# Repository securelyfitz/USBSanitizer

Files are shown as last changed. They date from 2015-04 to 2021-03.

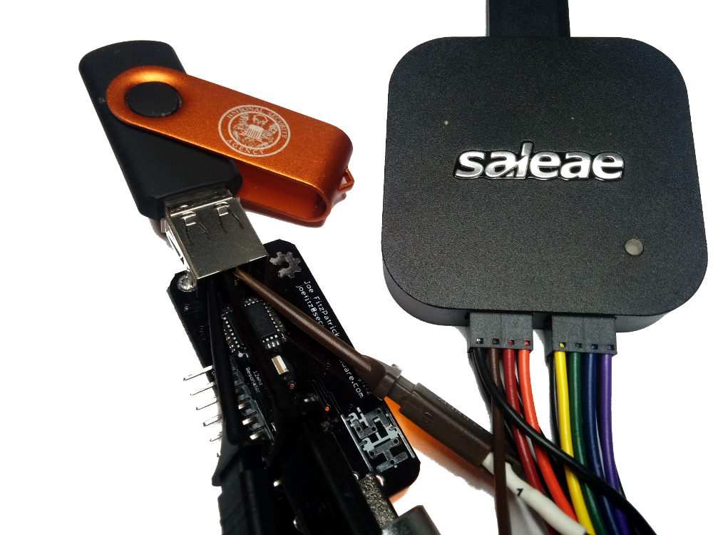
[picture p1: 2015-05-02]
Hushcon East/img/saleae.png

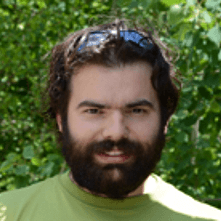
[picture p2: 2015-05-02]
Hushcon East/img/joe.png

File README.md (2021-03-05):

USB Sanitizer
================

A small and cheap standalone USB drive wiper

The code is based heavily on the USBHostGeneric example from FTDI as well as USB-Writeblocker by Phil Polstra

View 'slides' from hushcon:
https://rawgit.com/securelyfitz/USBSanitizer/master/Hushcon%20East/Hushcon%20East%20-%20USBSanitizer%20presentation.html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

Disclaimer:
-----------
USB sanitizer has some issues with a large number of USB drives right now. I should have an update shortly once i properly probe the SCSI device status/ready commands before writing...

Overview
---------
USB has issues, and being a very layered architecture, has layers of issues.

I deal with distributing class material on USB drives at security conferences, and prefer to reuse drives. At first i had a standalone air-gapped PC that did the job automatically when a drive was inserted, and more recently i have used a pogoplug modified for the purpose. This is overkill, and it's also not any guarantee that my air-gapped system that never gets any updates isn't vulnerable  to layers of potentially exploitable bugs.

After seeing how USB drives are used to transport information to air-gapped computers and learning that many securedrop sites use USB drives to transfer data to air-gapped computers, i realized that there is a broader use for a simple, standalone USB drive wiper.

Objective
---------
I aimed for a device that was:
- small (no larger than a usb drive itself)
- cheap ($5-10 BOM)
- bare metal (little or no OS)
- easy to build (Leaded SMT, single chip if possible)
- easy to code (cause i am teh suk at codez)
- easy to program ($50 programmer for a $5 board is lame)
 
Hardware
--------
- The main IC is the FTDI VNC2 which has a proprietary harvard architecture, proprietary 'RTOS', built in flash, and built in usb host capability. No other chip that i found under $10 had all that on a single chip.
- The board is 2.5x5cm. In addition to the VNC2, there is a single voltage regulator, a resonator, and a bunch of passive devices.
- Power is provided by the USB Male connector. Data pins are not connected to this connector in a normal build. If connected, this device can also be used with Phil Polstra's USB-Writeblocker: https://github.com/ppolstra/USB-Writeblocker
- A USB Female connector receives the flash drive (or even usb hdd/ssd).
- There is a 9 pin header for programming that can be unpopulated for production devices. Programming can be done via standard UART with hardware flow control.

Software
--------
FTDI provides an IDE and compiler for the VNC2 for windows only. It didn't run well on WINE on my initial attempts. The IDE can only be downloaded from them, without SSL. FTDI doesn't provide hashes of the executables either. If you're lucky enough to get the same embedded malware as me, your MD5s should be:
- http://www.ftdichip.com/Firmware/vnc2toolchain/Vinculum%20II%20Installer%20V2.0.0-SP1.exe
7b60bdc4313ed0449374dcaab23e0e84 
- http://www.ftdichip.com/Support/Utilities/VPROG.zip
ab5ec25792ef7a4f780aa507cd326ba5 
- http://www.ftdichip.com/Support/Utilities/FT_Prog_v3.0.60.276%20Installer.zip
f9a62778065ca541005dd138a52c5c99

FTDI provides an API for doing some basic USB stuff. They've got APIs to navigate filesystems and play audio files, but they're missing the ability to do basic things like query the capacity of a block storage device. Because of this i basically wrote everything at the raw USB level. I let the FTDI library take care of ACKs and NAKs but otherwise do most of the data transfer myself.

Everything about the VINCULUM is flakey - the IDE, the compiler, the hardware, the architecture in general. In retrospect there are probably more exploitable bugs in this bare-bones embedded device than there were in my air-gapped PC.

PCB Files
---------
* .sch and .brd: eagle schematic and board files 
* .lbr: eagle libraries for board outline and text items 
* .G* and .TXT: gerber files for fabricating board

Building:
------------------
See a video of building up a prototype. V1.0 is essentially the same, with the addition of a reset switch.

https://www.youtube.com/watch?v=V60TksZd7uk

Bill of Materials for ordering at digikey is in [USBSanitizer.csv]. Cost is $8.60 for a single set.

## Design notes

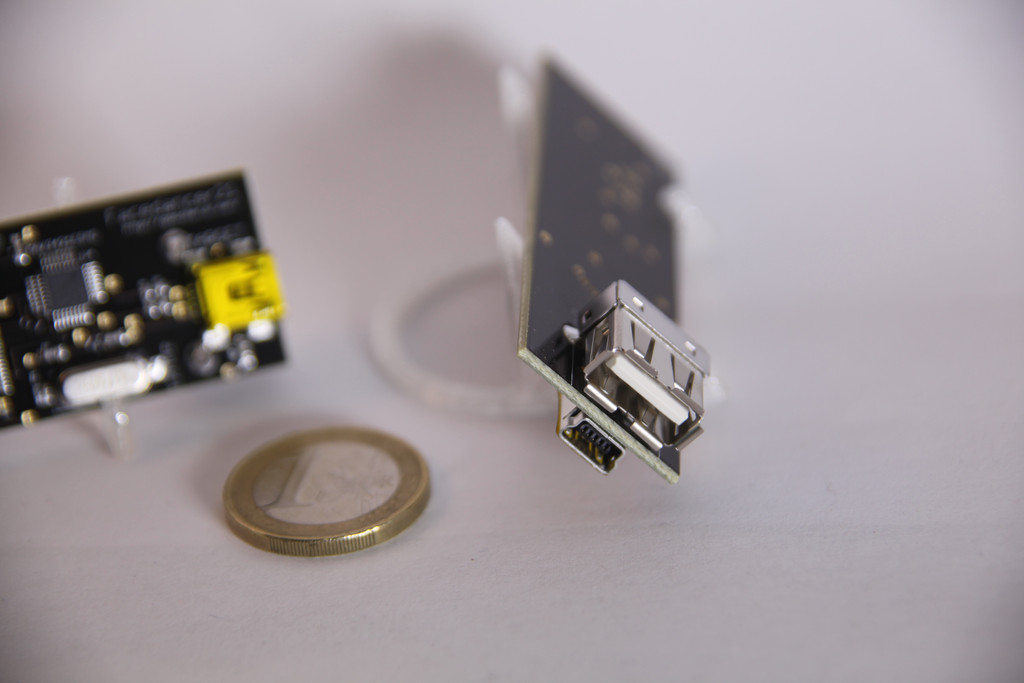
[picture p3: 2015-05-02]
Hushcon East/img/facedancer.jpg

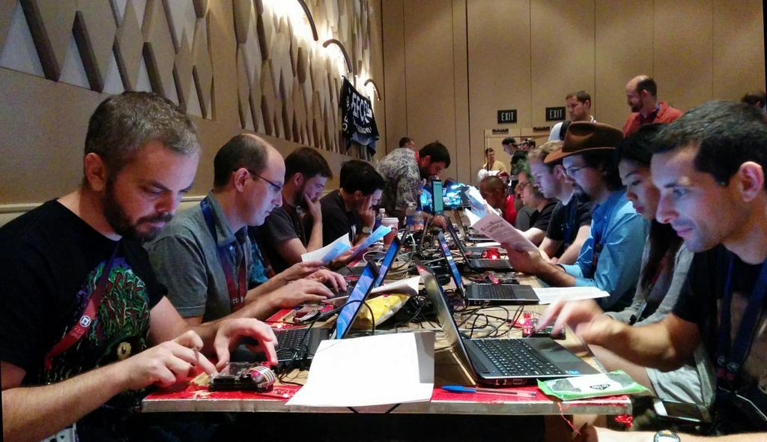
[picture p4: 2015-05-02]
Hushcon East/img/defcon.jpg

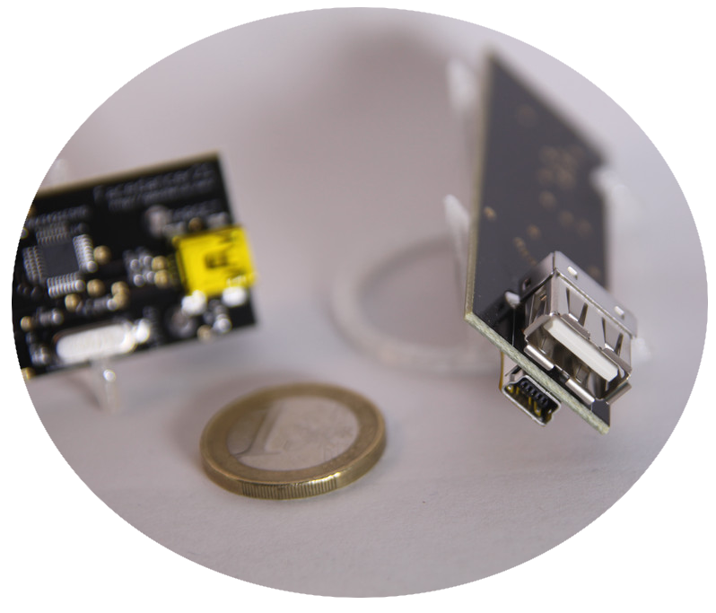
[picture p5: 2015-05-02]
Hushcon East/img/facedancer.png

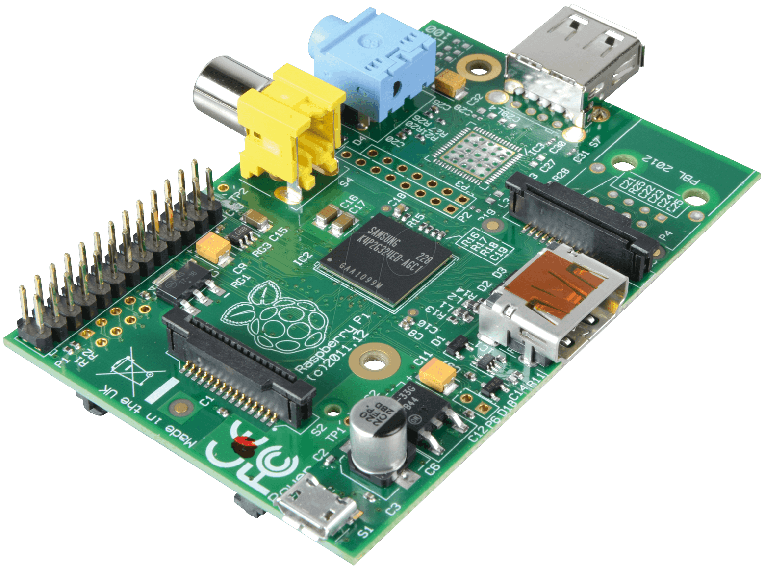
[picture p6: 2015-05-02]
Hushcon East/img/rpi.png

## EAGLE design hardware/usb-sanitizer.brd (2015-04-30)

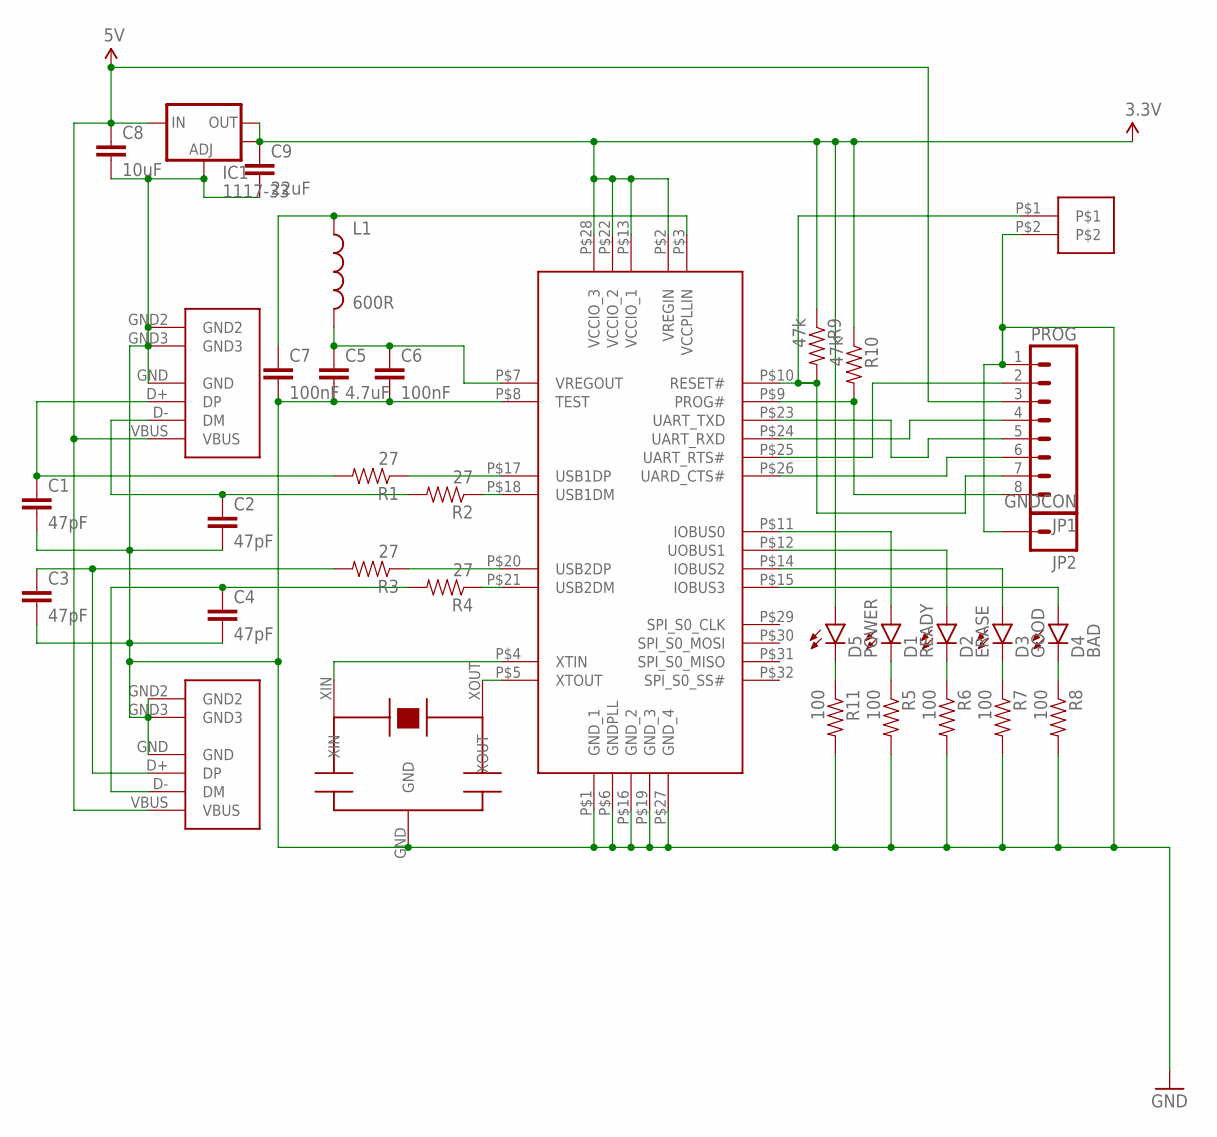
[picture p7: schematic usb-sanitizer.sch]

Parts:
C1, C2, C3, C4: 47pF; 0805
C5: 4.7uF; 0805
C6, C7: 100nF; 0805
C8: 10uF; 0805
C9: 22uF; 0805
D1: READY; 0805
D2: ERASE; 0805
D3: GOOD; 0805
D4: BAD; 0805
D5: POWER; 0805
IC1: 1117-33; SOT223
JP1: PROG; 1X08_LOCK
JP2: GNDCON; 1X01
L1: 600R; 0805
R1, R2, R3, R4: 27; 0805
R5, R6, R7, R8, R11: 100; 0805
R9, R10: 47k; 0805
U$1: VNC2; QFP32
U$4: RESONATOR
U$5: SWITCH
USB_FEMALE: USB_AF; USB-A-F
USB_MALE: USB_AM; USB-A-M

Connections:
3.3V: C9.1, D5.1 (A), IC1.2 (OUT), IC1.4 (OUT), R9.1, R10.1, U$1.P$2 (VREGIN), U$1.P$13 (VCCIO_1), U$1.P$22 (VCCIO_2), U$1.P$28 (VCCIO_3)
5V: C8.1, IC1.3 (IN), JP1.3, USB_FEMALE.VBUS, USB_MALE.VBUS
GND: C1.2, C2.2, C3.2, C4.2, C5.2, C6.2, C7.2, C8.2, C9.2, IC1.1 (ADJ), JP1.1, JP2.1, R5.2, R6.2, R7.2, R8.2, R11.2, U$1.P$1 (GND_1), U$1.P$6 (GNDPLL), U$1.P$8 (TEST), U$1.P$16 (GND_2), U$1.P$19 (GND_3), U$1.P$27 (GND_4), U$4.GND, U$5.P$2, USB_FEMALE.GND, USB_FEMALE.GND2, USB_FEMALE.GND3, USB_MALE.GND, USB_MALE.GND2, USB_MALE.GND3
unnamed: D5.2 (C), R11.1
unnamed: C5.1, C6.1, L1.2, U$1.P$7 (VREGOUT)
unnamed: C7.1, L1.1, U$1.P$3 (VCCPLLIN)
unnamed: U$1.P$5 (XTOUT), U$4.XOUT
unnamed: U$1.P$4 (XTIN), U$4.XIN
unnamed: JP1.2, U$1.P$25 (UART_RTS#)
unnamed: JP1.4, U$1.P$24 (UART_RXD)
unnamed: JP1.5, U$1.P$23 (UART_TXD)
unnamed: JP1.6, U$1.P$26 (UARD_CTS#)
unnamed: JP1.8, R10.2, U$1.P$9 (PROG#)
unnamed: JP1.7, R9.2, U$1.P$10 (RESET#), U$5.P$1
unnamed: D1.2 (C), R5.1
unnamed: D2.2 (C), R6.1
unnamed: D4.2 (C), R8.1
unnamed: D3.2 (C), R7.1
unnamed: D1.1 (A), U$1.P$11 (IOBUS0)
unnamed: D2.1 (A), U$1.P$12 (UOBUS1)
unnamed: D3.1 (A), U$1.P$14 (IOBUS2)
unnamed: D4.1 (A), U$1.P$15 (IOBUS3)
USB1DM: R2.1, U$1.P$18 (USB1DM)
USB1DP: R1.1, U$1.P$17 (USB1DP)
USB1RDM: C2.1, R2.2, USB_FEMALE.D- (DM)
USB1RDP: C1.1, R1.2, USB_FEMALE.D+ (DP)
USB2DM: R4.1, U$1.P$21 (USB2DM)
USB2DP: R3.1, U$1.P$20 (USB2DP)
USB2RDM: C4.1, R4.2, USB_MALE.D- (DM)
USB2RDP: C3.1, R3.2, USB_MALE.D+ (DP)

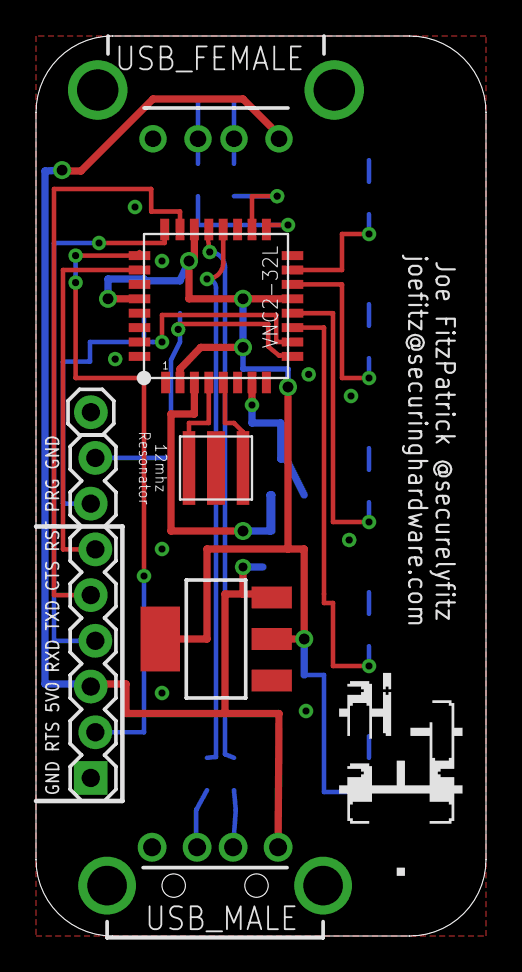
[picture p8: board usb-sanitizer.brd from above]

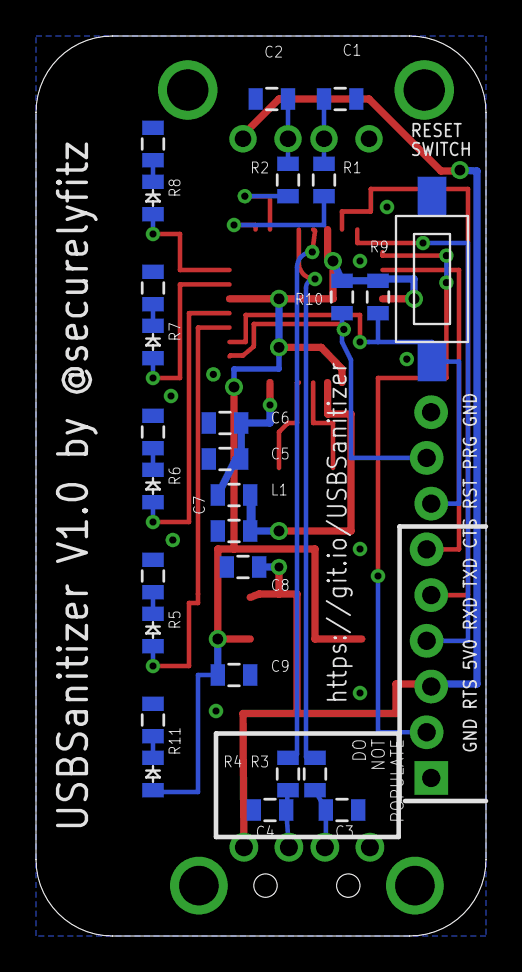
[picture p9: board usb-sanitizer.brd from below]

Board: 2 copper layers, 25.0 x 50.0 mm, 36 parts (27 on the bottom side), 30 nets.

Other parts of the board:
U$2: SH-HALFINCH
U$3: OSHW

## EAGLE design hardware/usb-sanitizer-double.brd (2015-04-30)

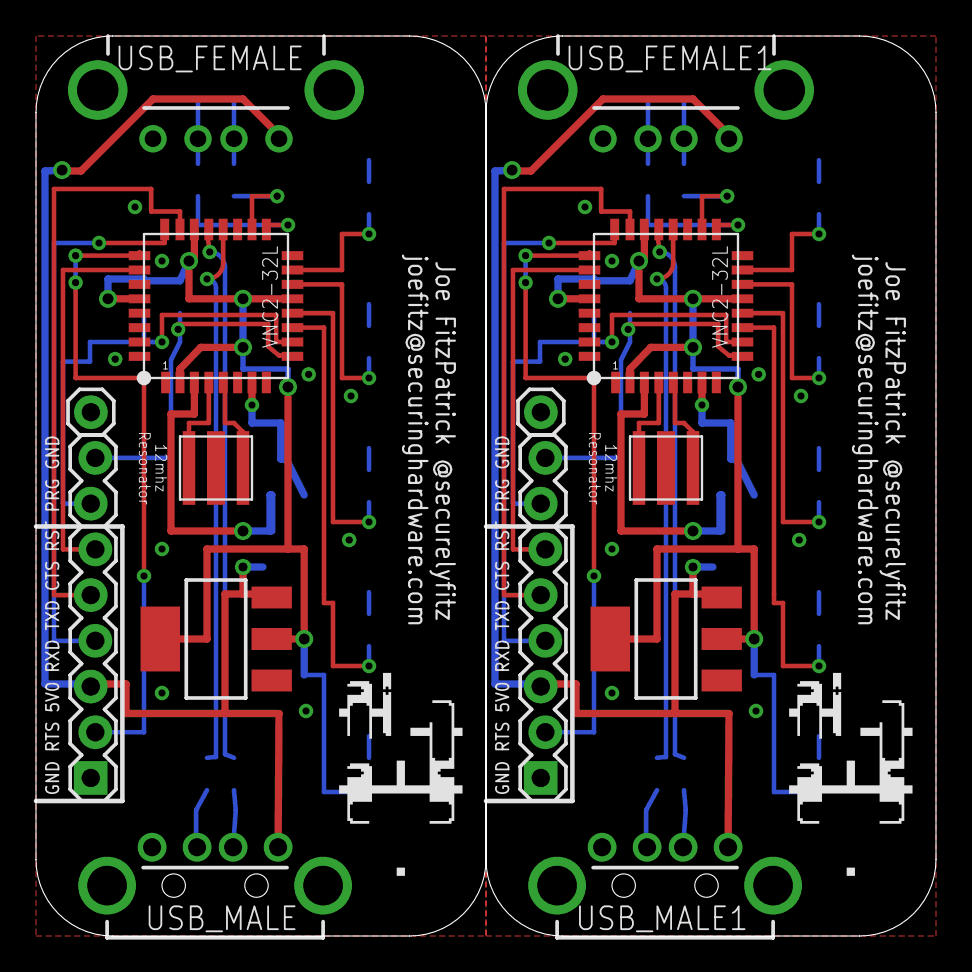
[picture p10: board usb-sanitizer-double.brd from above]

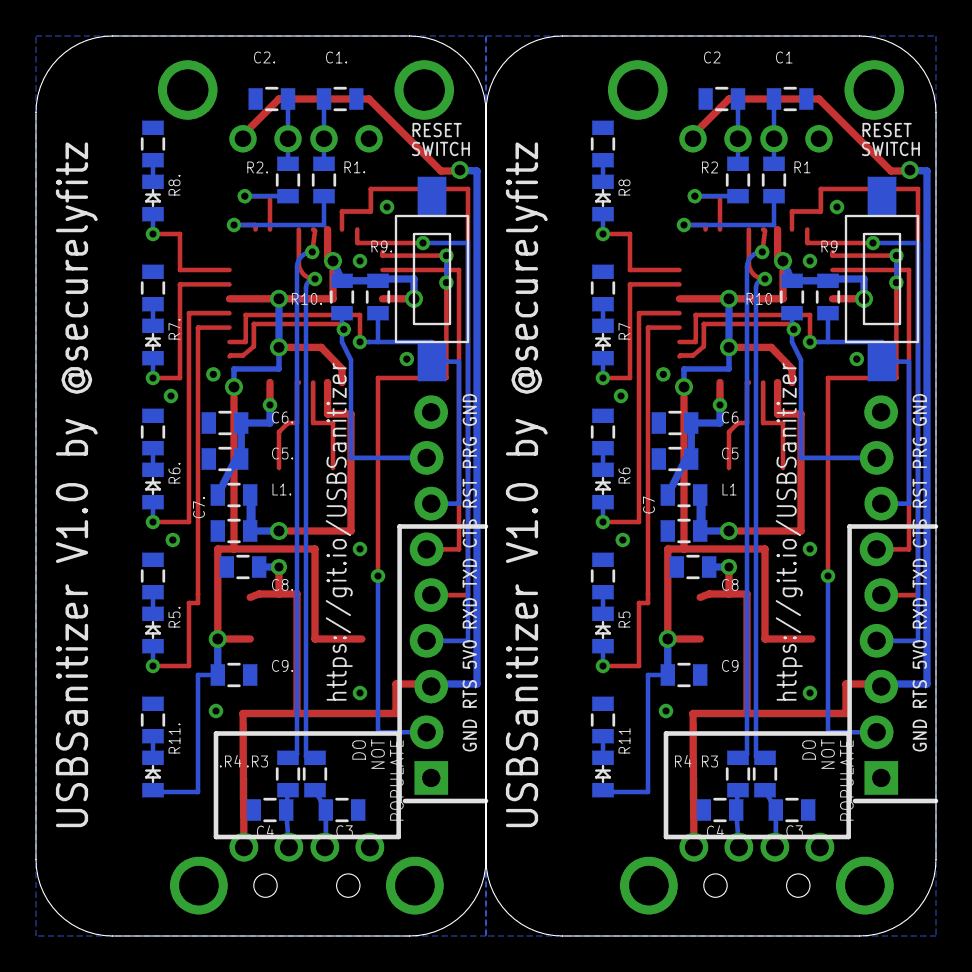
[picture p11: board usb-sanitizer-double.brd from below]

Board: 2 copper layers, 50.0 x 50.0 mm, 72 parts (54 on the bottom side), 60 nets.

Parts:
.C3, .C4: 47pF; 0805
.R3, .R4: 27; 0805
C1, C1., C2, C2., C3, C4: 47pF; 0805
C5, C5.: 4.7uF; 0805
C6, C6., C7, C7.: 100nF; 0805
C8, C8.: 10uF; 0805
C9, C9.: 22uF; 0805
D1, D6: READY; 0805
D2, D7: ERASE; 0805
D3, D8: GOOD; 0805
D4, D9: BAD; 0805
D5, D10: POWER; 0805
IC1, IC2: 1117-33; SOT223
JP1, JP3: PROG; 1X08_LOCK
JP2, JP4: GNDCON; 1X01
L1, L1.: 600R; 0805
R1, R1., R2, R2., R3, R4: 27; 0805
R5, R5., R6, R6., R7, R7., R8, R8., R11, R11.: 100; 0805
R9, R9., R10, R10.: 47k; 0805
U$1, U$6: VNC2; QFP32
U$2, U$8: SH-HALFINCH
U$3, U$9: OSHW
U$4, U$7: RESONATOR
U$5, U$10: SWITCH
USB_FEMALE, USB_FEMALE1: USB_AF; USB-A-F
USB_MALE, USB_MALE1: USB_AM; USB-A-M

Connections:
3.3V: C9.1, D5.1, IC1.2, IC1.4, R9.1, R10.1, U$1.P$2, U$1.P$13, U$1.P$22, U$1.P$28
3.3V1: C9..1, D10.1, IC2.2, IC2.4, R9..1, R10..1, U$6.P$2, U$6.P$13, U$6.P$22, U$6.P$28
5V: C8.1, IC1.3, JP1.3, USB_FEMALE.VBUS, USB_MALE.VBUS
5V1: C8..1, IC2.3, JP3.3, USB_FEMALE1.VBUS, USB_MALE1.VBUS
GND: C1.2, C2.2, C3.2, C4.2, C5.2, C6.2, C7.2, C8.2, C9.2, IC1.1, JP1.1, JP2.1, R5.2, R6.2, R7.2, R8.2, R11.2, U$1.P$1, U$1.P$6, U$1.P$8, U$1.P$16, U$1.P$19, U$1.P$27, U$4.GND, U$5.P$2, USB_FEMALE.GND, USB_FEMALE.GND2, USB_FEMALE.GND3, USB_MALE.GND, USB_MALE.GND2, USB_MALE.GND3
GND1: .C3.2, .C4.2, C1..2, C2..2, C5..2, C6..2, C7..2, C8..2, C9..2, IC2.1, JP3.1, JP4.1, R5..2, R6..2, R7..2, R8..2, R11..2, U$6.P$1, U$6.P$6, U$6.P$8, U$6.P$16, U$6.P$19, U$6.P$27, U$7.GND, U$10.P$2, USB_FEMALE1.GND, USB_FEMALE1.GND2, USB_FEMALE1.GND3, USB_MALE1.GND, USB_MALE1.GND2, USB_MALE1.GND3
unnamed: C5..1, C6..1, L1..2, U$6.P$7
unnamed: C7..1, L1..1, U$6.P$3
unnamed: U$6.P$5, U$7.XOUT
unnamed: U$6.P$4, U$7.XIN
unnamed: JP3.2, U$6.P$25
unnamed: JP3.4, U$6.P$24
unnamed: JP3.5, U$6.P$23
unnamed: JP3.6, U$6.P$26
unnamed: D5.2, R11.1
unnamed: C5.1, C6.1, L1.2, U$1.P$7
unnamed: C7.1, L1.1, U$1.P$3
unnamed: JP3.8, R10..2, U$6.P$9
unnamed: U$1.P$5, U$4.XOUT
unnamed: U$1.P$4, U$4.XIN
unnamed: JP1.2, U$1.P$25
unnamed: JP1.4, U$1.P$24
unnamed: JP1.5, U$1.P$23
unnamed: JP1.6, U$1.P$26
unnamed: JP3.7, R9..2, U$6.P$10, U$10.P$1
unnamed: JP1.8, R10.2, U$1.P$9
unnamed: JP1.7, R9.2, U$1.P$10, U$5.P$1
unnamed: D1.2, R5.1
unnamed: D2.2, R6.1
unnamed: D4.2, R8.1
unnamed: D3.2, R7.1
unnamed: D1.1, U$1.P$11
unnamed: D2.1, U$1.P$12
unnamed: D3.1, U$1.P$14
unnamed: D4.1, U$1.P$15
unnamed: D6.2, R5..1
unnamed: D7.2, R6..1
unnamed: D9.2, R8..1
unnamed: D8.2, R7..1
unnamed: D6.1, U$6.P$11
unnamed: D7.1, U$6.P$12
unnamed: D8.1, U$6.P$14
unnamed: D9.1, U$6.P$15
unnamed: D10.2, R11..1
USB1DM: R2.1, U$1.P$18
USB1DM1: R2..1, U$6.P$18
USB1DP: R1.1, U$1.P$17
USB1DP1: R1..1, U$6.P$17
USB1RDM: C2.1, R2.2, USB_FEMALE.D-
USB1RDM1: C2..1, R2..2, USB_FEMALE1.D-
USB1RDP: C1.1, R1.2, USB_FEMALE.D+
USB1RDP1: C1..1, R1..2, USB_FEMALE1.D+
USB2DM: R4.1, U$1.P$21
USB2DM1: .R4.1, U$6.P$21
USB2DP: R3.1, U$1.P$20
USB2DP1: .R3.1, U$6.P$20
USB2RDM: C4.1, R4.2, USB_MALE.D-
USB2RDM1: .C4.1, .R4.2, USB_MALE1.D-
USB2RDP: C3.1, R3.2, USB_MALE.D+
USB2RDP1: .C3.1, .R3.2, USB_MALE1.D+

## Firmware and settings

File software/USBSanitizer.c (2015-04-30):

/*
** Filename: USBSanitizer.c
**
** Automatically created by Application Wizard 2.0.2
** 
** Part of solution USBSanitizer in project USBSanitizer
**
** Comments: 
**
** Important: Sections between markers "FTDI:S*" and "FTDI:E*" will be overwritten by
** the Application Wizard
*/

#include "USBSanitizer.h"
#include "USBHostGenericDrv.h"

/* FTDI:STP Thread Prototypes */
vos_tcb_t *tcbFIRMWARE;

void firmware();
/* FTDI:ETP */

/* FTDI:SDH Driver Handles */
VOS_HANDLE hUSBHOST_1; // USB Host Port 1
VOS_HANDLE hGPIO_PORT_A; // GPIO Port A Driver
/* FTDI:EDH */

VOS_HANDLE hUSBHOSTGENERIC;            // USB Host Generic Driver (Additional Device)
extern usbhostGeneric_context_t *hostGenericCtx;

/* Declaration for IOMUx setup function */
void iomux_setup(void);

/* Main code - entry point to firmware */
void main(void)
{
	/* FTDI:SDD Driver Declarations */
	// GPIO Port A configuration context
	gpio_context_t gpioContextA;
	// USB Host configuration context
	usbhost_context_t usbhostContext;
	/* FTDI:EDD */

	/* FTDI:SKI Kernel Initialisation */
	vos_init(50, VOS_TICK_INTERVAL, VOS_NUMBER_DEVICES);
	vos_set_clock_frequency(VOS_48MHZ_CLOCK_FREQUENCY);
	vos_set_idle_thread_tcb_size(512);
	/* FTDI:EKI */

	iomux_setup();

	/* FTDI:SDI Driver Initialisation */
	// Initialise GPIO A
	gpioContextA.port_identifier = GPIO_PORT_A;
	gpio_init(VOS_DEV_GPIO_PORT_A,&gpioContextA);
	
	
	// Initialise USB Host
	usbhostContext.if_count = 8;
	usbhostContext.ep_count = 16;
	usbhostContext.xfer_count = 2;
	usbhostContext.iso_xfer_count = 2;
	usbhost_init(VOS_DEV_USBHOST_1, -1, &usbhostContext);
	/* FTDI:EDI */

	usbhostGeneric_init(VOS_DEV_USBHOSTGENERIC);
	
	/* FTDI:SCT Thread Creation */
	tcbFIRMWARE = vos_create_thread_ex(20, 4096, firmware, "Application", 0);
	/* FTDI:ECT */

	vos_start_scheduler();

main_loop:
	goto main_loop;
}

/* FTDI:SSP Support Functions */

unsigned char usbhost_connect_state(VOS_HANDLE hUSB)
{
	unsigned char connectstate = PORT_STATE_DISCONNECTED;
	usbhost_ioctl_cb_t hc_iocb;

	if (hUSB)
	{
		hc_iocb.ioctl_code = VOS_IOCTL_USBHOST_GET_CONNECT_STATE;
		hc_iocb.get        = &connectstate;
		vos_dev_ioctl(hUSB, &hc_iocb);

    // repeat if connected to see if we move to enumerated
		if (connectstate == PORT_STATE_CONNECTED)
		{
			vos_dev_ioctl(hUSB, &hc_iocb);
		}
	}
	return connectstate;
}

/* FTDI:ESP */

void open_drivers(void)
{
        /* Code for opening and closing drivers - move to required places in Application Threads */
        /* FTDI:SDA Driver Open */
        hUSBHOST_1 = vos_dev_open(VOS_DEV_USBHOST_1);
        hGPIO_PORT_A = vos_dev_open(VOS_DEV_GPIO_PORT_A);
        /* FTDI:EDA */
		
		hUSBHOSTGENERIC = vos_dev_open(VOS_DEV_USBHOSTGENERIC);

}

void attach_drivers(void)
{
        /* FTDI:SUA Layered Driver Attach Function Calls */
        /* FTDI:EUA */
}

void close_drivers(void)
{
        /* FTDI:SDB Driver Close */
        vos_dev_close(hUSBHOST_1);
        vos_dev_close(hGPIO_PORT_A);
        /* FTDI:EDB */
		
		vos_dev_close(hUSBHOSTGENERIC);

}



void writeString(VOS_HANDLE hDev, char *str)
{
	vos_dev_write(hDev, (unsigned char *) str, strlen(str), NULL);
}

void writeShort(VOS_HANDLE hDev, unsigned short val)
{
	char str[4];
	unsigned char ch;

	ch = val >> 12;
	ch = ch & 0x0f;

	if (ch > 9)
		str[0] = 'A' - 10 + ch;
	else
		str[0] = '0' + ch;

	ch = val >> 8;
	ch = ch & 0x0f;

	if (ch > 9)
		str[1] = 'A' - 10 + ch;
	else
		str[1] = '0' + ch;

	ch = val >> 4;
	ch = ch & 0x0f;

	if (ch > 9)
		str[2] = 'A' - 10 + ch;
	else
		str[2] = '0' + ch;

	ch = val & 0x0f;

	if (ch > 9)
		str[3] = 'A' - 10 + ch;
	else
		str[3] = '0' + ch;

	vos_dev_write(hDev, (unsigned char *) str, 4, NULL);
}
	
unsigned short send_cbw(boms_cbw_t *cbw)
{
	unsigned short num_written=0;
//	unsigned char status;
//	char *byteMsg = " Bytes written to device\r\n";

	usbhostGeneric_write((void*)cbw, sizeof(boms_cbw_t), &num_written, hostGenericCtx);
/*
	writeShort(hUART, (short)status);
	writeShort(hUART, num_written);
	writeString(hUART, byteMsg);		
*/
	return num_written;
}

unsigned short receive_data(void* buffer, unsigned short expected)
{
	unsigned short num_read;
//	unsigned char status;

//	char *byteMsg = " Bytes of read from device\r\n";

	usbhostGeneric_read(buffer, expected, &num_read, hostGenericCtx);
/*	
	writeShort(hUART, (short)status);
	writeShort(hUART, num_read);
	writeString(hUART, byteMsg);		
*/
	return num_read;
}
	
unsigned short receive_csw(boms_csw_t *csw)
{
	unsigned short num_read;

//	char *byteMsg = " Bytes of csw from device\r\n";

	usbhostGeneric_read((void*)csw, 13, &num_read, hostGenericCtx);
/*
	writeShort(hUART, num_read);
	writeString(hUART, byteMsg);		
*/
	return num_read;
}

void erase_block(unsigned long block_num)
{
	long deviceCapacity=0;
	short blockSize;
	unsigned short num_written=0;
	unsigned short num_data_written=0;
	unsigned short num_csw_read;
	boms_cbw_t cbw;
	boms_csw_t csw;
	unsigned char zeros[512];

	memset(cbw, 0, sizeof(boms_cbw_t));
	memset(cbw.cb.formated, 0, 16);
	memset(zeros, 0x41, 512);

	cbw.sig[0] = 'U'; //"USBS"
	cbw.sig[1] = 'S';
	cbw.sig[2] = 'B';
	cbw.sig[3] = 'S';
	cbw.tag = 0x0;
	cbw.dataTransferLength=0X100;
	cbw.flags=0x00;
	cbw.res1=0;
	cbw.lun=0;
	cbw.res2=0;
	cbw.cbLength=0x0A;
	cbw.cb.formated.command=0x2A;
	cbw.cb.raw[4]=block_num;
	cbw.cb.raw[8]=1;
	

	// send cbw to device
	usbhostGeneric_write((void*)&cbw, sizeof(boms_cbw_t), &num_written, hostGenericCtx);
	// send write data to device
	usbhostGeneric_write((void*)zeros, 512, &num_data_written, hostGenericCtx);
	// receive csw from device
	usbhostGeneric_read((void*)csw, 13, &num_csw_read, hostGenericCtx);

}
	
long get_read_capacity()
{
	long deviceCapacity=0;
	short blockSize;
	unsigned short num_written=0;
	unsigned short num_data_read;
	unsigned short num_csw_read;
	boms_cbw_t cbw;
	boms_csw_t csw;
	unsigned char buffer[8];	
	
	memset(cbw, 0, sizeof(boms_cbw_t));
	memset(cbw.cb.formated, 0, 16);
	memset(buffer, 0, sizeof(char)*8);

	cbw.sig[0] = 'U'; //"USBS"
	cbw.sig[1] = 'S';
	cbw.sig[2] = 'B';
	cbw.sig[3] = 'S';
	cbw.tag = 0x0;
	cbw.dataTransferLength=8;
	cbw.flags=0x80;
	cbw.res1=0;
	cbw.lun=0;
	cbw.res2=0;
	cbw.cbLength=0x0A;
	cbw.cb.formated.command=0x25;

	// send cbw to device
	usbhostGeneric_write((void*)&cbw, sizeof(boms_cbw_t), &num_written, hostGenericCtx);
	// receive response from device
	usbhostGeneric_read((void*)&buffer[0], 8, &num_data_read, hostGenericCtx);
	// receive csw from device
	usbhostGeneric_read((void*)csw, 13, &num_csw_read, hostGenericCtx);

	if (num_data_read==8)
	{
		deviceCapacity = buffer[0]*16777216 + buffer[1]*65536 + buffer[2]*256 +buffer[3];
		blockSize = buffer[4]*16777216 + buffer[5]*65536 + buffer[6]*256 +buffer[7];
	}
	return deviceCapacity;
}
	

void good_Light(unsigned int val)
{
	int i;
//	for (i=0;i<val;i++)
//	{
		vos_gpio_write_pin(GOOD, 1);
//		vos_delay_msecs(125);
		vos_gpio_write_pin(GOOD, 0);
//		vos_delay_msecs(125);
//	}
//	vos_delay_msecs(125);
}
	
void bad_Light(unsigned int val)
{
	int i;
	vos_gpio_write_pin(BAD, 1);
	while(1)
	{
		for (i=0;i<val;i++)
		{
			vos_gpio_write_pin(BAD, 1);
			vos_delay_msecs(166);
			vos_gpio_write_pin(BAD, 0);
			vos_delay_msecs(166);
		}
		vos_delay_msecs(500);
	}
}
	
/* Application Threads */

void firmware()
{
	unsigned long i;
	unsigned char status;
	unsigned char buf[64];
	unsigned short num_read;
	unsigned long block_count;
	char *readyMsg = "Ready!\r\n";
	char *colonMsg = ":";
	char *classMsg = "Class : ";
	char *crMsg = "\r\n";
	usbhostGeneric_ioctl_t generic_iocb;
	usbhostGeneric_ioctl_cb_attach_t genericAtt;
	usbhost_device_handle_ex ifDev;
	usbhost_device_handle_ex ifDev2;
	usbhost_ioctl_cb_t hc_iocb;
	usbhost_ioctl_cb_class_t hc_iocb_class;
	
	unsigned char portData;
	
	open_drivers();

	//set GPIO to OUT
	vos_gpio_set_port_mode(GPIO_PORT_A, 0xFF);
		
	//READY
	//flash until connect...
	do
	{
		vos_delay_msecs(125);
		vos_gpio_write_pin(READY, 0);
		vos_delay_msecs(125);
		vos_gpio_write_pin(READY, 1);
	}
	while ((usbhost_connect_state(hUSBHOST_1) != PORT_STATE_ENUMERATED));

		
	//device detected ready light on. count devices
	hc_iocb.ioctl_code = VOS_IOCTL_USBHOST_DEVICE_GET_NEXT_HANDLE;
	hc_iocb.handle.dif = NULL;
	hc_iocb.set = NULL;
	hc_iocb.get = &ifDev;

	if (vos_dev_ioctl(hUSBHOST_1, &hc_iocb) != USBHOST_OK)
	{
		bad_Light(1);
	}

	//look for second device. if it exists, then BAD
	hc_iocb.handle.dif = ifDev;
	hc_iocb.get = &ifDev2;
	if (vos_dev_ioctl(hUSBHOST_1, &hc_iocb) == USBHOST_OK)
	{
		bad_Light(2);
	}

	//only one device. What device class?
	hc_iocb.ioctl_code = VOS_IOCTL_USBHOST_DEVICE_GET_CLASS_INFO;
	hc_iocb.handle.dif = ifDev;
	hc_iocb.get = &hc_iocb_class;
	if (vos_dev_ioctl(hUSBHOST_1, &hc_iocb) != USBHOST_OK)
	{
		bad_Light(3);
	}

	if ((hc_iocb_class.dev_class != 0x08)||(hc_iocb_class.dev_subclass != 0x06)||(hc_iocb_class.dev_protocol != 0x50))
	{
		bad_Light(4);
	}

	// only one MSC. Connect
	genericAtt.hc_handle = hUSBHOST_1;
	genericAtt.ifDev = ifDev;
	generic_iocb.ioctl_code = VOS_IOCTL_USBHOSTGENERIC_ATTACH;
	generic_iocb.set.att = &genericAtt;
	if (vos_dev_ioctl(hUSBHOSTGENERIC, &generic_iocb) != USBHOSTGENERIC_OK)
	{
		bad_Light(5);
	}

	//connected. Get Capacity

	block_count=get_read_capacity();
	if (block_count==0)
	{
		bad_Light(6);
	}

	//connected. got capacity. write 0's
	for (i=0;i<=block_count;i++)
	{
		vos_gpio_write_pin(READY, (i+1)%2);
		vos_gpio_write_pin(ERASE, i%2);
		erase_block(i);
	}	

	//all done. turn off ready light. flash green then wait...
	vos_gpio_write_pin(READY, 0);
	for (i=0;i<10;i++)
	{
		vos_gpio_write_pin(ERASE, i%2);
		vos_gpio_write_pin(GOOD, i%2);
		vos_delay_msecs(50);
	}
	
	while ((usbhost_connect_state(hUSBHOST_1) == PORT_STATE_ENUMERATED))
	{
		vos_gpio_write_pin(GOOD, 1);
	}
}

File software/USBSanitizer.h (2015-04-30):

/*
** Filename: USBSanitizer.h
**
** Automatically created by Application Wizard 2.0.2
** 
** Part of solution USBSanitizer in project USBSanitizer
**
** Comments: 
**
** Important: Sections between markers "FTDI:S*" and "FTDI:E*" will be overwritten by
** the Application Wizard
*/

#ifndef _USBSanitizer_H_
#define _USBSanitizer_H_

#include "vos.h"
#include "BomsDefs.h"

#define READY GPIO_A_0
#define ERASE GPIO_A_1
#define GOOD GPIO_A_2
#define BAD GPIO_A_3


/* FTDI:SHF Header Files */
#include "USB.h"
#include "USBHost.h"
#include "GPIO.h"
#include "string.h"
#include "errno.h"
/* FTDI:EHF */

/* FTDI:SDC Driver Constants */
#define VOS_DEV_USBHOST_1 0
#define VOS_DEV_GPIO_PORT_A 1

#define VOS_NUMBER_DEVICES 3
/* FTDI:EDC */

// Additional Device Driver
#define VOS_DEV_USBHOSTGENERIC 2

/* FTDI:SXH Externs */
/* FTDI:EXH */

#endif /* _USBSanitizer_H_ */

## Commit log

2015-04-30 initial commit. Eagle board files, vinculum IDE files, and source files.
    [usb-sanitizer-double.brd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]
2015-04-30 adding readme and BOM:

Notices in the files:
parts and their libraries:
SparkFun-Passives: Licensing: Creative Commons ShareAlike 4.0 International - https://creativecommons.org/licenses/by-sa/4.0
